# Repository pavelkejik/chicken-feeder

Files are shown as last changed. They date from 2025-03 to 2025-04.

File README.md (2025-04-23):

# Smart Chicken Feeder
_An ESP32-powered accessory for automated feed control_

## Overview
This smart feeder is part of the Automated Chicken Coop Ecosystem. It operates wirelessly and autonomously to dispense food based on schedule, user commands, or weight target.

Powered by a battery-friendly ESP32-C3 and connected via **ESP-NOW** to the main coop door (gateway), the feeder ensures reliable long-term operation and seamless integration into the larger coop management system.

---

## Features
- **Scheduled feeding** with daily times and portion sizes
- **Feed-to-weight** mode using integrated load-cell
- **ESP-NOW** communication for ultra-low power use
- Battery-powered, optimized for deep sleep
- OTA firmware updates via the coop door gateway
- Status reported via MQTT (via gateway) and visible in Web UI

---

## Hardware
| Component | Purpose |
|---|---|
| ESP32-C3 | Low-power microcontroller with Wi-Fi and ESP-NOW |
| Load Cell + HX711 | Measure feed weight in grams |
| Servo Motor | Open/close feed flap |
| 18650 Li-Ion + Charger | Power supply for standalone use |

All components are enclosed in a 3D-printable case. STL files and PCB design are in the `hw/` directory.

---

## Communication
### ESP-NOW
- Feeder registers with the door (gateway)

### MQTT (via Gateway)
```text
<base_topic>/devices/<feeder-id>/state/weight_g        = 175
<base_topic>/devices/<feeder-id>/set/feed_g            ← 50
<base_topic>/devices/<feeder-id>/set/mode              ← "schedule" | "weight"
```

---

## Power Management
- Sleeps between operations using deep sleep
- Wakeup on timer or servo/feed command
- Runtime per charge depends on feeding frequency

---

## OTA Updates
- Triggered remotely via the coop door
- Uses ESP-NOW for wire-free, zero-setup OTA

---

## Getting Started
1. Flash firmware using PlatformIO:
   ```bash
   cd firmware
   pio run -t upload
   ```
2. Power up the feeder and press the pairing button once.
3. In the Web UI (at `dvirka.local`), go to **Accessories > New > Pair**.
4. Once connected, it will appear in the dashboard.

---

## Author
**Pavel Kejík**  
Part of the Automated Coop Ecosystem – see main project: [chicken-door](https://github.com/pavelkejik/chicken-door)

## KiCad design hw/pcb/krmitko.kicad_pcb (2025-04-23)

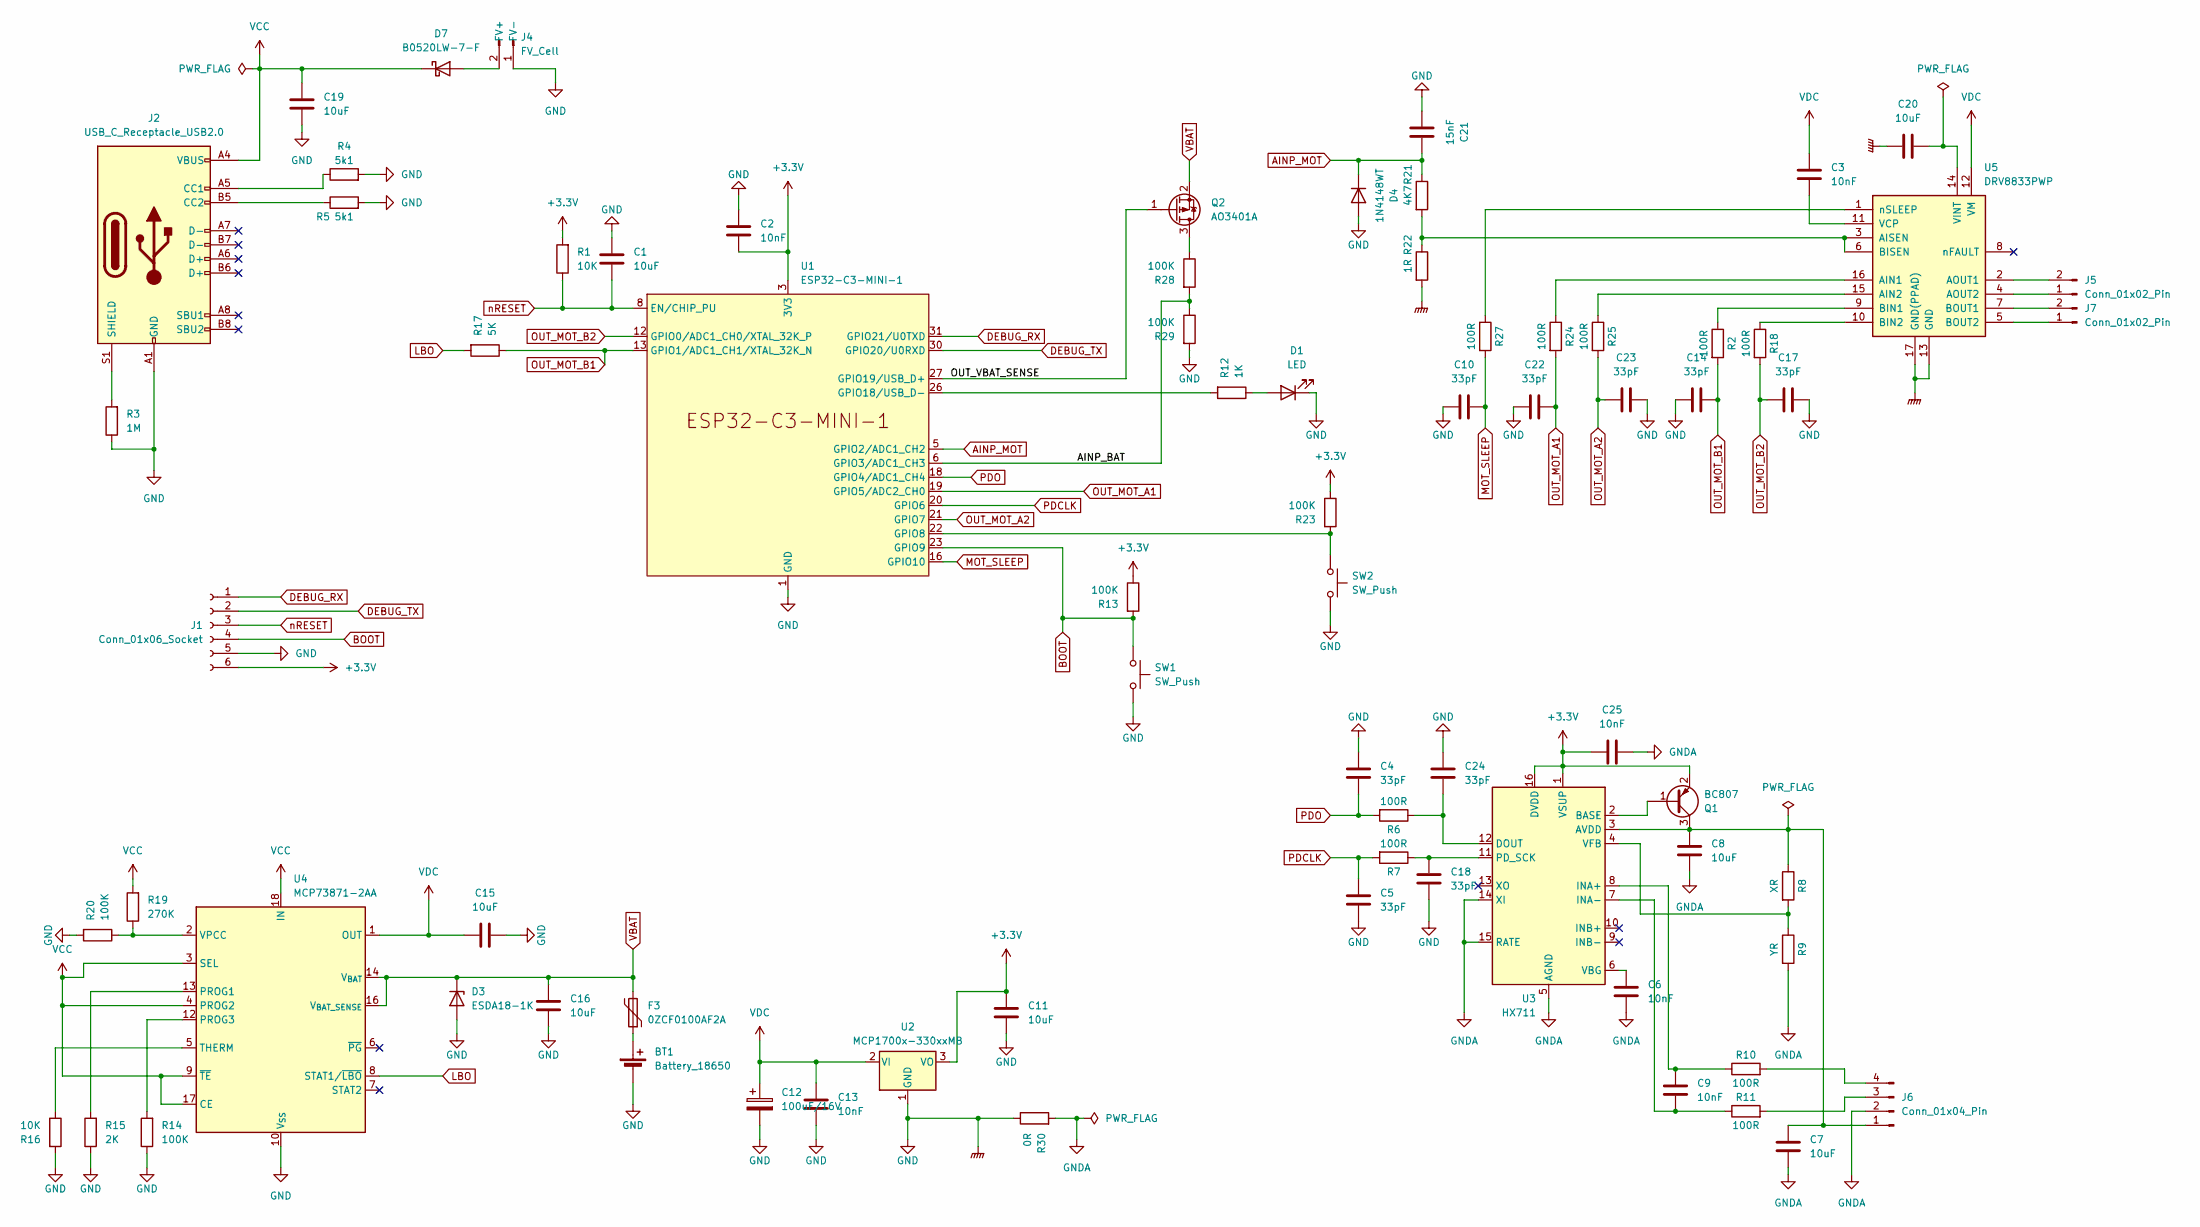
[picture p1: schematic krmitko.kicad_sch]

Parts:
BT1: Battery_18650; BatteryHolder_MPD_BH-18650-PC2
C1, C7, C8, C11, C15, C16, C19, C20: 10uF; C_0805_2012Metric_Pad1.18x1.45mm_HandSolder
C2, C3, C6, C9, C13, C25: 10nF; C_0805_2012Metric_Pad1.18x1.45mm_HandSolder
C4, C5, C10, C14, C17, C18, C22, C23, C24: 33pF; C_0805_2012Metric_Pad1.18x1.45mm_HandSolder
C12: 100uF/16V; CP_Elec_6.3x7.7
C21: 15nF; C_0805_2012Metric_Pad1.18x1.45mm_HandSolder
D1: LED; LED_1210_3225Metric_Pad1.42x2.65mm_HandSolder
D3: ESDA18-1K; D_SMA
D4: 1N4148WT; D_SOD-123F
D7: B0520LW-7-F; D_SOD-123
F3: 0ZCF0100AF2A; Fuse_2920_7451Metric_Pad2.10x5.45mm_HandSolder
J1: Conn_01x06_Socket; PinHeader_1x06_P2.54mm_Vertical
J2: USB_C_Receptacle_USB2.0; USB_C_Receptacle_GCT_USB4105-xx-A_16P_TopMnt_Horizontal
J4: FV_Cell; Molex_KK-254_AE-6410-02A_1x02_P2.54mm_Vertical
J5, J7: Conn_01x02_Pin; Molex_KK-254_AE-6410-02A_1x02_P2.54mm_Vertical
J6: Conn_01x04_Pin; Molex_KK-254_AE-6410-04A_1x04_P2.54mm_Vertical
Q1: BC807; SOT-23
Q2: AO3401A; SOT-23
R1, R16: 10K; R_0805_2012Metric_Pad1.20x1.40mm_HandSolder
R2, R6, R7, R10, R11, R18, R24, R25, R27: 100R; R_0805_2012Metric_Pad1.20x1.40mm_HandSolder
R3: 1M; R_0805_2012Metric_Pad1.20x1.40mm_HandSolder
R4, R5: 5k1; R_0805_2012Metric_Pad1.20x1.40mm_HandSolder
R8: XR; R_0805_2012Metric_Pad1.20x1.40mm_HandSolder
R9: YR; R_0805_2012Metric_Pad1.20x1.40mm_HandSolder
R12: 1K; R_0805_2012Metric_Pad1.20x1.40mm_HandSolder
R13, R14, R20, R23, R28, R29: 100K; R_0805_2012Metric_Pad1.20x1.40mm_HandSolder
R15: 2K; R_0805_2012Metric_Pad1.20x1.40mm_HandSolder
R17: 5K; R_0805_2012Metric_Pad1.20x1.40mm_HandSolder
R19: 270K; R_0805_2012Metric_Pad1.20x1.40mm_HandSolder
R21: 4K7; R_0805_2012Metric_Pad1.20x1.40mm_HandSolder
R22: 1R; R_0805_2012Metric_Pad1.20x1.40mm_HandSolder
R30: 0R; R_0805_2012Metric_Pad1.20x1.40mm_HandSolder
SW1, SW2: SW_Push; SW_Tactile_SPST_Angled_PTS645Vx58-2LFS
U1: ESP32-C3-MINI-1
U2: MCP1700x-330xxMB; SOT-89-3
U3: HX711; SOP-16_3.9x9.9mm_P1.27mm
U4: MCP73871-2AA; QFN-20-1EP_4x4mm_P0.5mm_EP2.5x2.5mm
U5: DRV8833PWP; HTSSOP-16-1EP_4.4x5mm_P0.65mm_EP3.4x5mm_Mask2.46x2.31mm_The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

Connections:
+3.3V: C2.2, C11.2, C25.2, J1.6, Q1.2 (E), R1.2, R13.1, R23.1, U1.3 (3V3), U2.3 (VO), U3.1 (VSUP), U3.16 (DVDD)
/AINP_BAT: R28.2, R29.1, U1.6 (GPIO3/ADC1_CH3)
/OUT_VBAT_SENSE: Q2.1 (G), U1.27 (GPIO19/USB_D+)
AINP_MOT: C21.2, D4.1 (K), R21.1, U1.5 (GPIO2/ADC1_CH2)
BOOT: J1.4, R13.2, SW1.1, U1.23 (GPIO9)
DEBUG_RX: J1.1, U1.31 (GPIO21/U0TXD)
DEBUG_TX: J1.2, U1.30 (GPIO20/U0RXD)
GND: BT1.2 (-), C1.1, C2.1, C4.1, C5.2, C10.1, C11.1, C12.2, C13.1, C14.1, C15.2, C16.1, C17.2, C18.2, C19.2, C20.1, C21.1, C22.1, C23.2, C24.1, D1.1 (K), D3.2 (A), D4.2 (A), J1.5, J2.A1 (GND), J2.A12 (GND), J2.B1 (GND), J2.B12 (GND), J4.1 (FV-), R3.1, R4.2, R5.2, R14.1, R15.1, R16.2, R20.2, R22.2, R29.2, R30.1, SW1.2, SW2.2, U1.1 (GND), U1.2 (GND), U1.11 (GND), U1.14 (GND), U1.36 (GND), U1.37 (GND), U1.38 (GND), U1.39 (GND), U1.40 (GND), U1.41 (GND), U1.42 (GND), U1.43 (GND), U1.44 (GND), U1.45 (GND), U1.46 (GND), U1.47 (GND), U1.48 (GND), U1.49 (GND), U1.50 (GND), U1.51 (GND), U1.52 (GND), U1.53 (GND), U2.1 (GND), U4.10 (V_{SS}), U4.11 (V_{SS}), U4.21 (V_{SS}), U5.13 (GND), U5.17 (GND(PPAD))
GNDA: C6.1, C7.1, C8.1, C25.1, J6.2, R9.2, R30.2, U3.5 (AGND), U3.14 (XI), U3.15 (RATE)
LBO: R17.2, U4.8 (STAT1/~LBO)
MOT_SLEEP: C10.2, R27.2, U1.16 (GPIO10)
unnamed: BT1.1 (+), F3.1
unnamed: D1.2 (A), R12.1
unnamed: D7.2 (A), J4.2 (FV+)
unnamed: J2.A5 (CC1), R4.1
unnamed: J2.B5 (CC2), R5.1
unnamed: J2.S1 (SHIELD), R3.2
unnamed: J5.1, U5.4 (AOUT2)
unnamed: J5.2, U5.2 (AOUT1)
unnamed: C7.2, C8.2, J6.1, Q1.3 (C), R8.1, U3.3 (AVDD)
unnamed: J6.3, R11.2
unnamed: J6.4, R10.2
unnamed: J7.1, U5.5 (BOUT2)
unnamed: J7.2, U5.7 (BOUT1)
unnamed: Q1.1 (B), U3.2 (BASE)
unnamed: Q2.3 (D), R28.1
unnamed: R23.2, SW2.1, U1.22 (GPIO8)
unnamed: R12.2, U1.26 (GPIO18/USB_D-)
unnamed: C24.2, R6.1, U3.12 (DOUT)
unnamed: C9.2, R10.1, U3.8 (INA+)
unnamed: C9.1, R11.1, U3.7 (INA-)
unnamed: C18.1, R7.1, U3.11 (PD_SCK)
unnamed: C6.2, U3.6 (VBG)
unnamed: R8.2, R9.1, U3.4 (VFB)
unnamed: R15.2, U4.13 (PROG1)
unnamed: R14.2, U4.12 (PROG3)
unnamed: R16.1, U4.5 (THERM)
unnamed: R19.1, R20.1, U4.2 (VPCC)
unnamed: R24.1, U5.16 (AIN1)
unnamed: R25.1, U5.15 (AIN2)
unnamed: R21.2, R22.1, U5.3 (AISEN), U5.6 (BISEN)
unnamed: R2.1, U5.9 (BIN1)
unnamed: R18.1, U5.10 (BIN2)
unnamed: C3.1, U5.11 (VCP)
unnamed: C20.2, U5.14 (VINT)
unnamed: R27.1, U5.1 (nSLEEP)
OUT_MOT_A1: C22.2, R24.2, U1.19 (GPIO5/ADC2_CH0)
OUT_MOT_A2: C23.1, R25.2, U1.21 (GPIO7)
OUT_MOT_B1: C14.2, R2.2, R17.1, U1.13 (GPIO1/ADC1_CH1/XTAL_32K_N)
OUT_MOT_B2: C17.1, R18.2, U1.12 (GPIO0/ADC1_CH0/XTAL_32K_P)
PDCLK: C5.1, R7.2, U1.20 (GPIO6)
PDO: C4.2, R6.2, U1.18 (GPIO4/ADC1_CH4)
VBAT: C16.2, D3.1 (K), F3.2, Q2.2 (S), U4.14 (V_{BAT}), U4.15 (V_{BAT}), U4.16 (V_{BAT_SENSE})
VCC: C19.1, D7.1 (K), J2.A4 (VBUS), J2.A9 (VBUS), J2.B4 (VBUS), J2.B9 (VBUS), R19.2, U4.3 (SEL), U4.4 (PROG2), U4.9 (~TE), U4.17 (CE), U4.18 (IN), U4.19 (IN)
VDC: C3.2, C12.1, C13.2, C15.1, U2.2 (VI), U4.1 (OUT), U4.20 (OUT), U5.12 (VM)
nRESET: C1.2, J1.3, R1.1, U1.8 (EN/CHIP_PU)

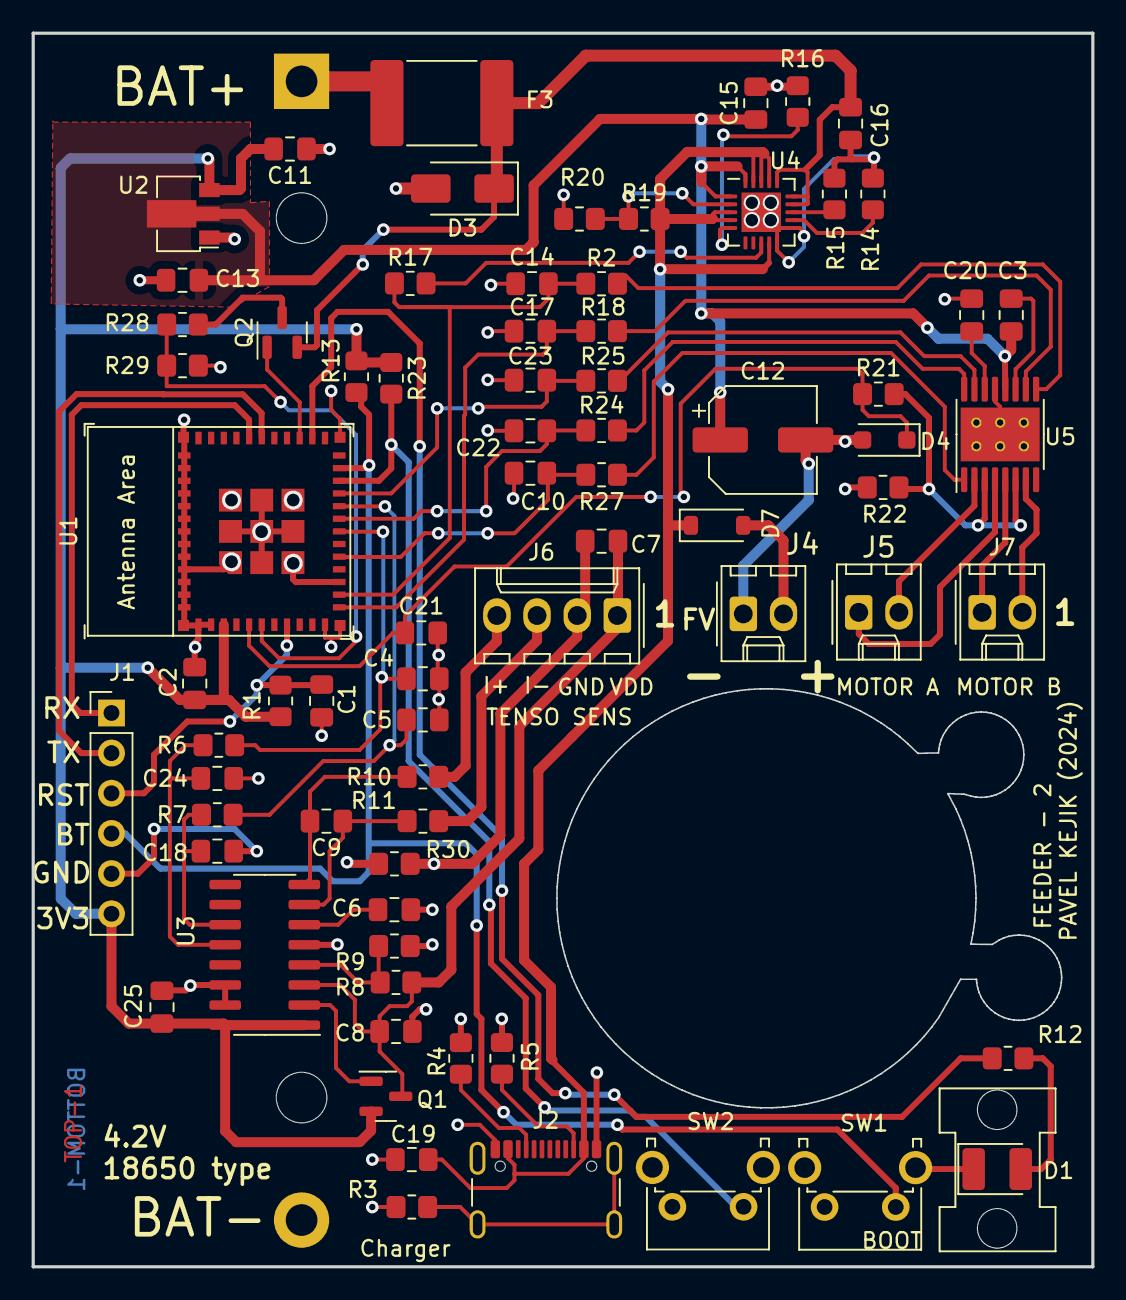
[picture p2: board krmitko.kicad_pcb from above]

Board: 2 copper layers, 67.0 x 78.0 mm, 75 parts (1 on the bottom side), 56 nets.

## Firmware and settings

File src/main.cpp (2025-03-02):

/***********************************************************************
 * Filename: main.cpp
 * Author: Pavel Kejik
 * Date: 2024-04-12
 * Description:
 *     This file serves as the entry point for the application, 
 *     setting up and managing all hardware and software components. 
 *     It initializes modules such as ESP-NOW as well as handling device management and logging 
 *     The program controls various tasks for feeder management, system logging and 
 *     deep sleep control, incorporating extensive use of FreeRTOS for task management.
 *
 ***********************************************************************/

#include <Arduino.h>
#include "button.h"
#include "led.h"
#include "pin_map.h"
#include "motor.h"
#include "parameters.h"
#include "error.h"
#include "log.h"
#include "feeder_ctrl.h"
#include "common.h"
#include <esp_now.h>
#include "esp32c3/rom/rtc.h"
#include <LittleFS.h>
#include "esp_now_client.h"
#include "time_ctrl.h"
#include "FreeRTOSConfig.h"
#include "esp_freertos_hooks.h"
#include "deep_sleep_ctrl.h"
#include "weight.h"

#define TIME_SCHEDULE(_t_secs) ((uint32_t)((_t_secs) * 1000 / COMMON_LOOP_TASK_PERIOD_MS))

Button btn1(BTN_1, INPUT);
Button btn2(BTN_2, INPUT);
Led LedR(LED_R);
Motor motor(MOT_A1, MOT_A2, MOT_SLEEP, MOT_ISENSE);
Weight weight;

static uint32_t btn_timer;
void MotorTask(void *pvParameters)
{
  while (true)
  {
    motor.Run();
    delay(MOTOR_CONTROL_TASK_PERIOD_MS);
  }
}

void FeederControlTask(void *pvParameters)
{
  while (true)
  {
    FeederCtrl::Task();
    delay(FEEDER_CONTROL_TASK_PERIOD_MS);
  }
}

void LedControlTask(void *pvParameters)
{
  delay(100);
  LedR = 0;
  delay(500);
  while (true)
  {
    if (motor.IsLowBattery())
    {
      LedR = 0x11;
    }
    else if (StavZarizeni.Get() == Vybrano)
    {
      LedR = 0xff;
      LedR.SetDimming();
    }
    else if (StavZarizeni.Get() == Parovani)
    {
      LedR = 0xff;
      LedR.SetDimming();
    }
    else if (StavZarizeni.Get() == Sparovano)
    {
      LedR = 0;
      delay(500);
      LedR = 0x0CCC;
      StavZarizeni.Set(NormalniMod);
      delay(800);
      LedR = 0;
      delay(2000);
    }
    else
    {
      switch (StavKrmitka.Get())
      {
      case NeznaznamaPoloha:
        LedR = 0;
        break;
      case Otevirani:
      case Zavirani:
      case UvolneniOtevirani:
      case UvolneniZavirani:
        LedR = 0x1111;
        break;
      case Otevreno:
      case Zavreno:
        LedR = 0;
        break;
      case StopZavirani:
      case StopOtevirani:
        LedR = 0;
        break;
      case ChybaKrmitka:
        LedR = 0x01;
        break;
      default:
        break;
      }
    }
    delay(100);
  }
}

void ledUpdate(void)
{
  LedR.CtrlTask();
}

void SystemLogTask(void *pvParameters)
{
  while (true)
  {
    SystemLog::Task();

    delay(200);
  }
}

void ESPNowTask(void *pvParameters)
{
  while (true)
  {
    ESPNowCtrl::Task();
    // delayMicroseconds(100);
  }
}

void ESPNowSlaveTask(void *pvParameters)
{
  while (true)
  {
    ESPNowClient::Task();
  }
}

void TimeControlTask(void *pvParameters)
{
  while (true)
  {
    TimeCtrl::Task();
    delay(TIME_CONTROL_TASK_PERIOD_MS);
  }
}

void CommandProcessingTask(void *pvParameters)
{
  while (true)
  {
    active_tasks[Write_Command_Task] = true;
    weight.Task();
    active_tasks[Write_Command_Task] = false;
    xSemaphoreTake(write_cmd_sem, pdMS_TO_TICKS(1000));
  }
}


void SleepTask(void *pvParameters)
{
  while (true)
  {
    if (IsSystemIdle())
    {
      vTaskSuspendAll();
      for (int i = 0; i < NUMBER_TASK_HANDLES; i++)
      {
        if (active_task_handle[i] != 0)
        {
          vTaskDelete(active_task_handle[i]);
        }
      }
      xTaskResumeAll();
      Register::Sleep();
      motor.Sleep();
      SystemLog::Sleep();
      if (RestartCmd.Get() == povoleno)
      {
        ESP.restart();
      }
      else
      {
        ESPNowClient::Sleep();
        esp_sleep_enable_timer_wakeup(PeriodaKomunikace_S.Get() * 1000000ULL);
        pinMode(BTN_WAKE, INPUT);
        esp_deep_sleep_enable_gpio_wakeup(BIT(BTN_WAKE), ESP_GPIO_WAKEUP_GPIO_LOW);
        gpio_hold_en((gpio_num_t)PDCLK);
        gpio_deep_sleep_hold_en();
        esp_deep_sleep_start();
      }
    }
    delay(10);
  }
}

void setup()
{
  Serial.begin(115200);
  Register::InitAll();
  storageFS.begin(true, "/storage", 5);

  SystemLog::Init();
  Error::ClearAll();
  btn1.Init();
  btn2.Init();
  LedR.Init();
  motor.Init();
  weight.Init();
  FeederCtrl::Init();
  TimeCtrl::Init();
  ESPNowClient::Init();
  active_tasks[Button_Task] = false;

  switch (rtc_get_reset_reason(0))
  {
  case 1:
    ResetReason.Set(rst_Poweron);
    break;
  case 3:
  case 12:
    ResetReason.Set(rst_Software);
    break;
  case 5:
    ResetReason.Set(rst_Deepsleep);
    break;
  case 4:
  case 7:
  case 8:
  case 9:
  case 11:
  case 13:
  case 16:
    ResetReason.Set(rst_Watchdog);
    break;
  case 15:
    ResetReason.Set(rst_Brownout);
    break;

  case 14:
    ResetReason.Set(rst_External);

  default:
    ResetReason.Set(rst_Unknown);
  }

  if (esp_sleep_get_gpio_wakeup_status())
  {
    active_tasks[Button_Task] = true;
    StartTimer(btn_timer, TIME_SCHEDULE(10));
    LedR = 0xffff;
  }

  memset(active_task_handle, 0, sizeof(active_task_handle));

  xTaskCreateUniversal(MotorTask, "motorTask", getArduinoLoopTaskStackSize(), NULL, 4, &active_task_handle[0], ARDUINO_RUNNING_CORE);
  xTaskCreateUniversal(FeederControlTask, "feederCtrlTask", getArduinoLoopTaskStackSize(), NULL, 2, &active_task_handle[1], ARDUINO_RUNNING_CORE);
  xTaskCreateUniversal(LedControlTask, "ledCtrlTask", getArduinoLoopTaskStackSize(), NULL, 1, &active_task_handle[2], ARDUINO_RUNNING_CORE);
  xTaskCreateUniversal(SystemLogTask, "logTask", getArduinoLoopTaskStackSize(), NULL, 1, &active_task_handle[3], ARDUINO_RUNNING_CORE);
  xTaskCreateUniversal(CommandProcessingTask, "cmdTask", getArduinoLoopTaskStackSize(), NULL, 1, &active_task_handle[4], ARDUINO_RUNNING_CORE);
  xTaskCreateUniversal(TimeControlTask, "timeCtrlTask", getArduinoLoopTaskStackSize(), NULL, 2, &active_task_handle[5], ARDUINO_RUNNING_CORE);
  xTaskCreateUniversal(ESPNowTask, "espNowTask", getArduinoLoopTaskStackSize(), NULL, 5, NULL, ARDUINO_RUNNING_CORE);
  xTaskCreateUniversal(ESPNowSlaveTask, "espNowSlaveTask", getArduinoLoopTaskStackSize(), NULL, 1, &active_task_handle[6], ARDUINO_RUNNING_CORE);
  xTaskCreateUniversal(SleepTask, "sleepTask", getArduinoLoopTaskStackSize(), NULL, 1, NULL, ARDUINO_RUNNING_CORE);

  // esp_register_freertos_idle_hook(IdleTask);

  hw_timer_t *timer = NULL;
  timer = timerBegin(0, 80, true);
  timerAttachInterrupt(timer, &ledUpdate, true);
  timerAlarmWrite(timer, LED_CTRL_TIME_MS * 1000, true);
  timerAlarmEnable(timer);
}

void loop()
{
  btn1.Read();
  btn2.Read();

  if (btn1.IsOnEvent())
  {
    StartTimer(btn_timer, TIME_SCHEDULE(10));
    // SystemLog::Print();
    switch (StavKrmitka.Get())
    {
    case Otevreno:
    case NeznaznamaPoloha:
      FeederCtrl::EventSourced(ev_close, povel_tlacitkem);
      break;

    case Zavreno:
      break;

    default:
      FeederCtrl::Event(ev_stop);
      break;
    }
  }

  if (btn2.IsOnEvent())
  {
    active_tasks[Button_Task] = true;
    StartTimer(btn_timer, TIME_SCHEDULE(10));
    // SystemLog::Print();
    switch (StavKrmitka.Get())
    {
    case Zavreno:
    case NeznaznamaPoloha:
      FeederCtrl::EventSourced(ev_open, povel_tlacitkem);
      break;

    case Otevreno:
      break;

    default:
      FeederCtrl::Event(ev_stop);
      break;
    }
  }

  if (btn2.IsLongOnEvent())
  {
    active_tasks[Button_Task] = true;
    StartTimer(btn_timer, TIME_SCHEDULE(60));
    ESPNowClient::StartPairing();
  }

  if (EndTimer(btn_timer))
  {
    active_tasks[Button_Task] = false;
  }
    delay(COMMON_LOOP_TASK_PERIOD_MS);
}

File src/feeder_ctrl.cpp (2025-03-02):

/***********************************************************************
 * Filename: feeder_ctrl.cpp
 * Author: Pavel Kejik
 * Date: 2024-04-12
 * Description:
 *     Defines event processing functions for the finite state machine 
 *     in the FeederCtrl class.
 *
 ***********************************************************************/

#include <feeder_ctrl.h>
#include "led.h"
#include "motor.h"
#include "log.h"
#include "error.h"
#include "deep_sleep_ctrl.h"
#include "weight.h"

#define TIME_SCHEDULE(_t_secs) ((uint32_t)((_t_secs) * 1000 / FEEDER_CONTROL_TASK_PERIOD_MS))

std::atomic<uint32_t> FeederCtrl::events;
uint32_t FeederCtrl::timer;

extern Motor motor;
extern Weight weight;

const char *const cmd_source_txt[] = {
    "",
    "(Tlacitkem)",
    "(Casem)",
    "(ESP-NOW)",
    "(Doplneni krmiva)",
    ""};

FeederState_t noaction()
{
    return NOSTATE;
}

FeederState_t feeder_error()
{
    SystemLog::PutLog("Chyba krmitka", v_error);
    motor.Stop();
    FeederCtrl::TimerStop();
    return ChybaKrmitka;
}

FeederState_t closed()
{
    SystemLog::PutLog("Zavreno", v_info);
    motor.Stop();
    error_close.Clear();
    PosledniCasZavreni_S.Set(Now());
    FeederCtrl::TimerStop();
    return Zavreno;
}

FeederState_t opened()
{
    SystemLog::PutLog("Otevreno", v_info);
    motor.Stop();
    error_open.Clear();
    PosledniCasOtevreni_S.Set(Now());
    FeederCtrl::TimerStop();
    weight.RunMeasure();
    return Otevreno;
}

FeederState_t check_open()
{
    motor.Close();
    FeederCtrl::TimerStart(2);
    return OvereniOtevreni;
}

FeederState_t check_open_current()
{
    if (AktualniProud_mA.Get() > ZERO_CURRENT_THRESHOLD_mV)
    {
        return opened();
    }
    else
    {
        return feeder_error();
    }
}

FeederState_t check_close()
{
    motor.Open();
    FeederCtrl::TimerStart(1);
    return OvereniZavreni;
}

FeederState_t check_close_current()
{

    if (AktualniProud_mA.Get() > ZERO_CURRENT_THRESHOLD_mV)
    {
        return closed();
    }
    else
    {
        return feeder_error();
    }
}

FeederState_t stop()
{
    SystemLog::PutLog("Stop", v_info);

    motor.StopFast();
FeederCtrl::TimerStop();
    return NeznaznamaPoloha;
}

FeederState_t break_close()
{
    // SystemLog::PutLog("Stop", v_info);

    motor.Stop();

    FeederCtrl::TimerStart(3);

    return StopZavirani;
}

FeederState_t break_open()
{
    motor.Stop();

    FeederCtrl::TimerStart(2);

    return StopOtevirani;
}

FeederState_t repeat_open()
{
    SystemLog::PutLog("Opakovani otevreni", v_info);
    motor.Open();
    FeederCtrl::TimerStart(MAX_OPEN_CLOSE_TIME_S);
    return Otevirani;
}

FeederState_t repeat_close()
{
    SystemLog::PutLog("Opakovani zavreni", v_info);
    motor.Close();
    FeederCtrl::TimerStart(MAX_OPEN_CLOSE_TIME_S);
    return Zavirani;
}

FeederState_t unable_open()
{
    motor.Stop();

    if (error_open.Check(true))
    {
        return feeder_error();
    }

    delay(500);
    FeederCtrl::TimerStart(3);
    motor.Close();
    return UvolneniOtevirani;
}

FeederState_t to_close()
{
    SystemLog::PutLog("Zavirani " + String(cmd_source_txt[PovelOd.Get()]), v_info);
    motor.Close();
    FeederCtrl::TimerStart(MAX_OPEN_CLOSE_TIME_S);
    return Zavirani;
}

FeederState_t unable_close()
{
    motor.Stop();

    if (error_close.Check(true))
    {
        return feeder_error();
    }

    delay(500);
    FeederCtrl::TimerStart(3);
    motor.Open();
    return UvolneniZavirani;
}

FeederState_t to_open()
{
    SystemLog::PutLog("Otevirani " + String(cmd_source_txt[PovelOd.Get()]), v_info);
    motor.Open();
    FeederCtrl::TimerStart(MAX_OPEN_CLOSE_TIME_S);
    return Otevirani;
}

//                     Stop      Otevrit    Zavrit    pretizeni otev     pretizeni zav    bez proudu      time expired
#undef State
#define State(_state_, _ev_stop, _ev_open, _ev_close, _ev_overload_up, _ev_overload_down, _ev_no_current, _ev_timer_expired) \
    {_ev_stop, _ev_open, _ev_close, _ev_overload_up, _ev_overload_down, _ev_no_current, _ev_timer_expired},

const state_fun_t FeederCtrl::state_fun[nmr_states][nmr_events] =
    {
#include "feeder_ctrl_table.h"
};

void FeederCtrl::execute()
{
    if (EndTimer(timer))
    {
        Event(ev_timer_expired);
    }

    // std::lock_guard<std::mutex> lock(events_mutex);
    if (events != 0)
    {
        for (int i = first_event; i < nmr_events; i++)
        {
            uint32_t event_mask = 1 << i;
            if (events & event_mask)
            {
                FeederState_t state = state_fun[StavKrmitka.Get()][i]();
                if (state != NOSTATE)
                {
                    SetState(state);
                }
                events &= ~event_mask;
            }
        }
    }
    else
    {
        if (motor.IsStopped() && !IsTimerRunning(timer))
        {
            active_tasks[Position_Task] = false;
        }
    }
}

void FeederCtrl::Init(void)
{
    active_tasks[Position_Task] = true;
}

bool FeederCtrl::IsState(FeederState_t state)
{
    return (FeederState_t)StavKrmitka.Get() == state;
}
void FeederCtrl::SetState(FeederState_t state)
{
    StavKrmitka.Set(state);
}

void FeederCtrl::TimerStart(uint32_t secs)
{
    StartTimer(timer, TIME_SCHEDULE(secs));
}

void FeederCtrl::TimerStop()
{
    StopTimer(timer);
}

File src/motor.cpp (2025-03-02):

/***********************************************************************
 * Filename: motor.cpp
 * Author: Pavel Kejik
 * Date: 2024-04-12
 * Description:
 *     Implements the Motor class.
 * 
 ***********************************************************************/


#include "Arduino.h"
#include "common.h"
#include "motor.h"
#include "pin_map.h"
#include "parameters.h"
#include "error.h"

void Motor::ReadCurrent(void)
{
    int32_t curr = analogReadMilliVolts(pinISense);
    AktualniProud_mA.Set(current.Input(curr));
    // Serial.println(curr);
}

void ReadBatteryVoltage(void)
{
    digitalWrite(BAT_NSENSE, LOW);
    delay(5);
    uint32_t bat_v = analogReadMilliVolts(BAT_AINP);
    delay(1);
    bat_v += analogReadMilliVolts(BAT_AINP);
    bat_v *= (BAT_RDIVIDER_R_UP + BAT_RDIVIDER_R_DOWN);
    bat_v /= (BAT_RDIVIDER_R_DOWN * 2);

    int32_t last_bat_v = (uint16_t)NapetiBaterie_mV.Get() & 0x7FFF;
    if (last_bat_v != 0)
    {
                bat_v = last_bat_v + ((int32_t)bat_v - last_bat_v) / 8;
    }
    if (!digitalRead(LBO))
    {
        bat_v = bat_v | (1 << 15);
    }
    NapetiBaterie_mV.Set((int32_t)bat_v);
    // Serial.println(NapetiBaterie_mV.Get());
    digitalWrite(BAT_NSENSE, HIGH);
}

void Motor::Init(void)
{
    pinMode(pinOpen, OUTPUT);
    pinMode(pinClose, OUTPUT);
    pinMode(pinSleep, OUTPUT);
    pinMode(BAT_NSENSE, OUTPUT);
    pinMode(LBO, INPUT_PULLUP);

    digitalWrite(BAT_NSENSE, HIGH);

    digitalWrite(pinSleep, HIGH);
    analogSetPinAttenuation(pinISense, ADC_0db);
    adcAttachPin(pinISense);
    adcAttachPin(BAT_AINP);
    ReadBatteryVoltage();
    Stop();
}

void Motor::Open(void)
{
    state = motor_to_open;
    digitalWrite(pinSleep, HIGH);
    delay(10);

    Error::ClearActionAll(MOVE_UP | MOVE_DOWN);
    digitalWrite(pinOpen, HIGH);
    digitalWrite(pinClose, LOW);
}

void Motor::Close(void)
{
    state = motor_to_close;
    digitalWrite(pinSleep, HIGH);
    delay(10);
    Error::ClearActionAll(MOVE_UP | MOVE_DOWN);
    digitalWrite(pinOpen, LOW);
    digitalWrite(pinClose, HIGH);
}

void Motor::StopFast(void)
{
    digitalWrite(pinOpen, HIGH);
    digitalWrite(pinClose, HIGH);
    delay(10);
    digitalWrite(pinSleep, LOW);
    state = motor_faststop;
}

void Motor::Stop(void)
{
    digitalWrite(pinOpen, LOW);
    digitalWrite(pinClose, LOW);
    delay(10);
    digitalWrite(pinSleep, LOW);
    state = motor_stop;
}

void Motor::Sleep(void)
{
    digitalWrite(pinSleep, LOW);
}

void Motor::Run(void)
{
    ReadCurrent();

    switch (state)
    {
    case motor_to_open:
        ovrl_open.Check(AktualniProud_mA.Get() > MotorMaxProud_mA.Get());
        ovrl_close.Check(false);
        no_current.Check(AktualniProud_mA.Get() < ZERO_CURRENT_THRESHOLD_mV);
        break;

    case motor_to_close:
        ovrl_close.Check(AktualniProud_mA.Get() > MotorMaxProud_mA.Get());
        ovrl_open.Check(false);
        no_current.Check(AktualniProud_mA.Get() < ZERO_CURRENT_THRESHOLD_mV);
        break;

    default:
        ovrl_open.Check(false);
        ovrl_close.Check(false);
        no_current.Check(false);
        break;
    }
}

bool Motor::IsLowBattery(void)
{
    return NapetiBaterie_mV.Get() < LOW_BATTERY_THRESHOLD;
}

bool Motor::IsStopped(void)
{
    return (state == motor_stop) || (state == motor_faststop);
}
